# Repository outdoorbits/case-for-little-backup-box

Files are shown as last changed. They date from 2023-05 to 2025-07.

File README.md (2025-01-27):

# Case for little backup box

This project provides a housings for little backup box based on a <a href="Raspberry_Pi_zero_2W">Raspberry Pi zero 2W</a>, <a href="Raspberry_Pi_4">Raspberry Pi 4B</a> or <a href="Raspberry_Pi_5">Raspberry Pi 5</a>.<br>

## Housings for Raspberry Pi 4B and Raspberry Pi 5
They are based on a 3D drawing on the <a href="https://www.freecad.org">freeCAD</a> platform. This drawing can be easily adjusted using an integrated table of dimensions.<br>
<br>
<br>
For more information visit <a href="https://github.com/outdoorbits/little-backup-box">outdoorbits/little-backup-box</a>. In lbb's <a href="https://github.com/outdoorbits/little-backup-box/wiki">Wiki</a> you will find all information needed to plug it all together.</a>
<br>
<figure align="center">
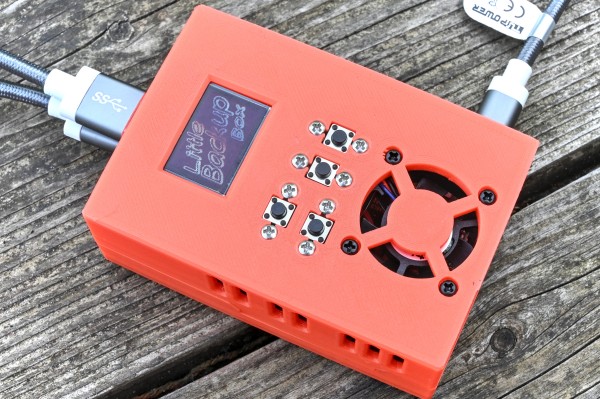
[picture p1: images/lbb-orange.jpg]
	
	<figcaption>Little Backup Box in this case, including a ssd1331 color display, buttons for menu-navigation and a pwm-controlled fan</figcaption>
</figure>
<br>
<h2>The standard drawings assumes the following components:</h2>
<ol>
	<li>Raspberry Pi 4 Model B or Raspberry Pi 5</li>
	<li>Display ssd1331 (RGB color display with 96x64 pixels, 1.3&quot;)</li>
	<li>Fan having external dimensions 30x30mm, hole spacing 24mm; prefer PMW-versions</li>
	<li>Micro key buttons 6x6 mm2, mounted on a board</li>
	<li>15 pieces of jumper wire, female</li>
	<li>4 screws M2.5 x 20 mm for the case</li>
	<li>8 screws M2.0 x 6 mm and nuts for the buttons</li>
	<li>Hot glue to stick the display</li>
</ol>

<h2>Customize drawing</h2>
If you use different hardware components, you can adapt the drawing.
It's (relatively) easy to adjust dimensions:
<ol>
	<li>Open the FCStd file with freeCAD</li>
	<li>Open the "dim" spreadsheet in the tree view</li>
	<li>Change the appropriate dimensions</li>
	<li>Mark the respective body in the tree view (e.g. "Bottom")</li>
	<li>Export the stl file (File - export...)</li>
</ol>

<br>
<figure align="center">
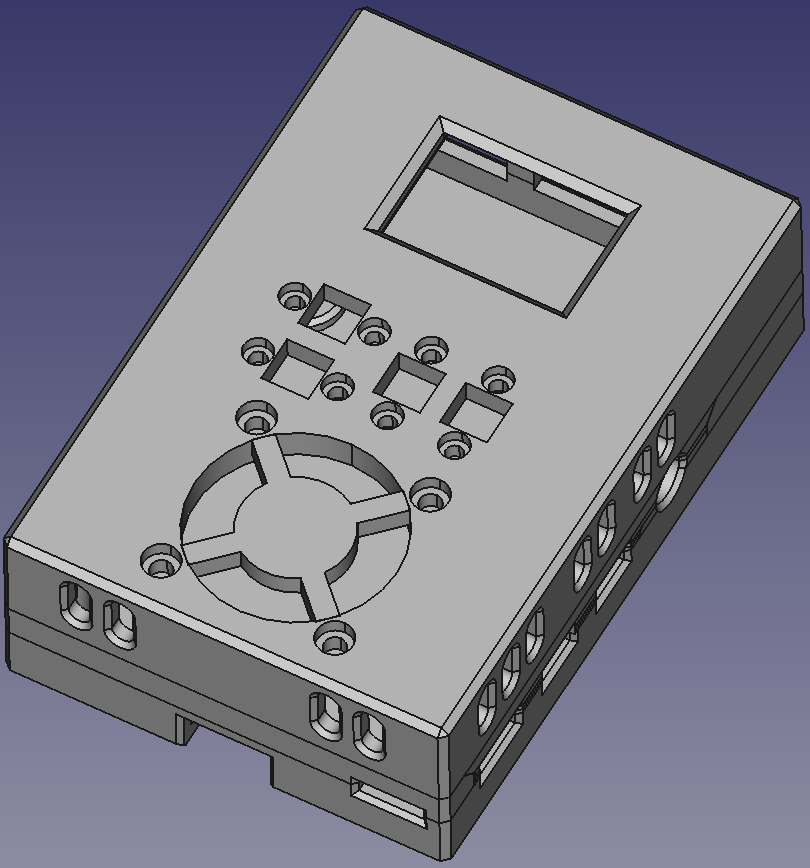
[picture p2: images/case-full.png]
	
	<figcaption>The whole case</figcaption>
</figure>

<figure align="center">
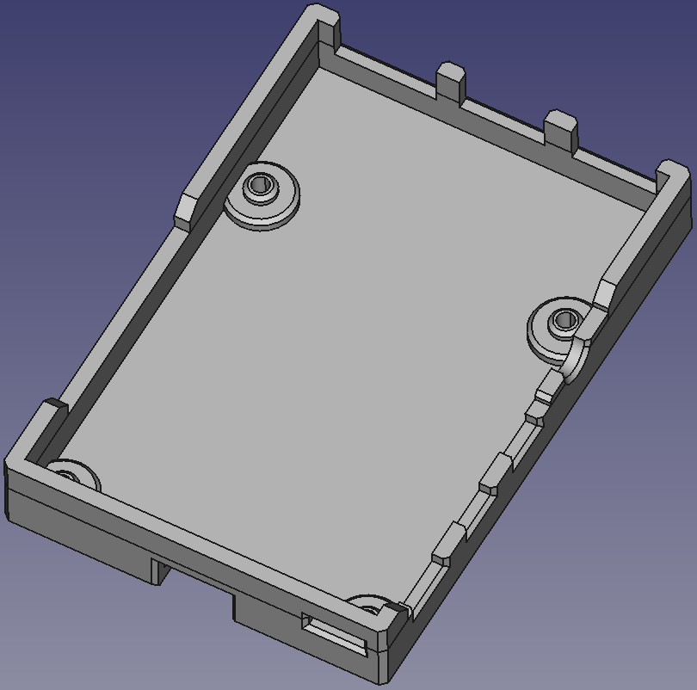
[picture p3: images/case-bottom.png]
	
	<figcaption>The bottom</figcaption>
</figure>

<figure align="center">
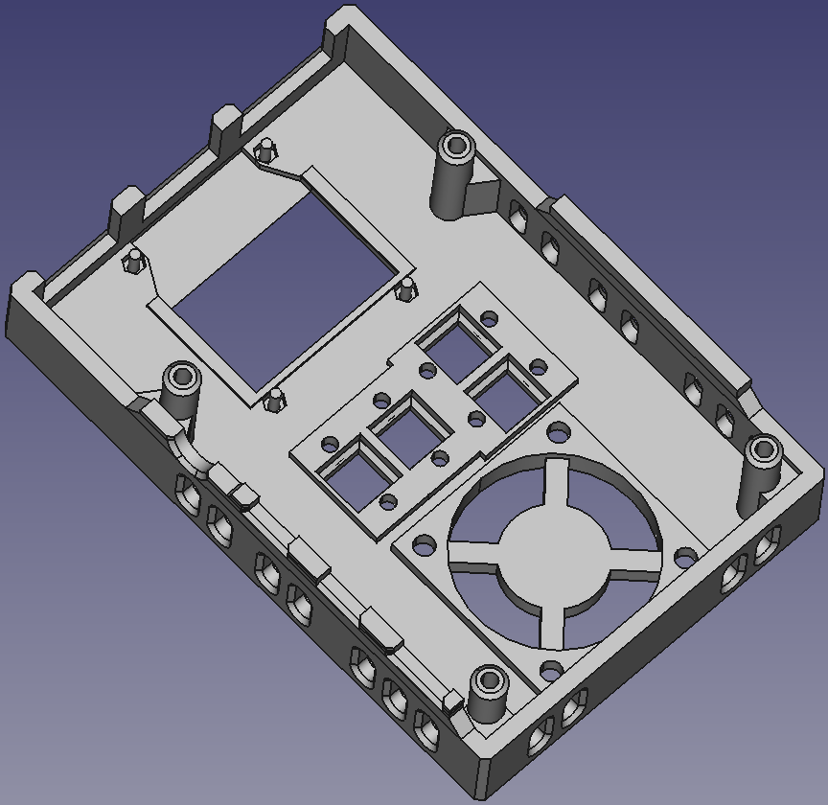
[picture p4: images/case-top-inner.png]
	
	<figcaption>Inside view of the top</figcaption>
</figure>

<figure align="center">
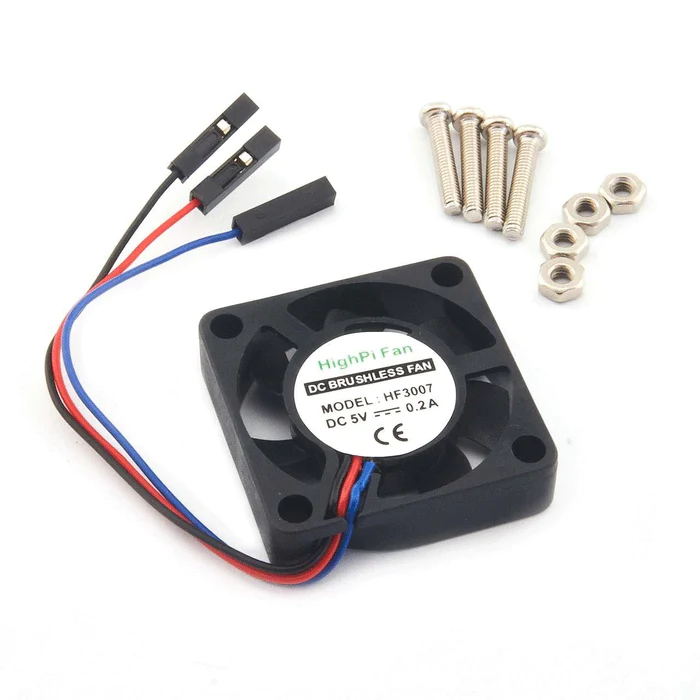
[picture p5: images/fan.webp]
	
	<figcaption>Fan, look for &quot;<a href="https://thepihut.com/products/highpi-pro-5v-fan-software-controlled">5V Fan - Software-Controlled</a>&quot;</figcaption>
</figure>

<figure align="center">
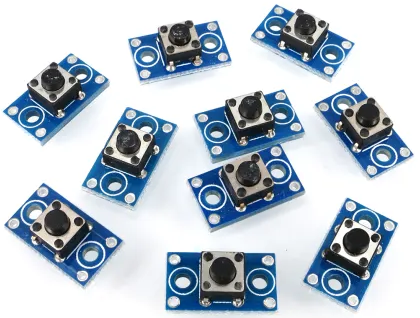
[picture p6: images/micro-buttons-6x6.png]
	
	<figcaption>Mico buttons, look for &quot;<a href="https://eckstein-shop.de/10xMicroKeyTaster6x6mmButtonsModuleRastermaC39F22C54mm12V2F50mA">Micro key button</a>&quot;</figcaption>
</figure>

## Housing for Raspberry Pi zero 2W
<figure>
	<a href="Raspberry_Pi_zero_2W">
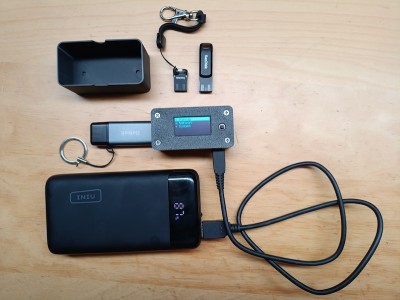
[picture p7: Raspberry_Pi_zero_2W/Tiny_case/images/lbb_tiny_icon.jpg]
		
	</a>
	<figcaption>Ultra tiny and well protected housing for Raspberry Pi 2W</figcaption>
</figure><br />
<br />
<br />

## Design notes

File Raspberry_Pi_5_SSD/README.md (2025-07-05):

[Thelightdecides](https://github.com/thelightdecides) presents several highly interesting versions of Little Backup Box on his [website](https://www.thelightdecides.com/travel-photography-blog/little-backup-box-simple-reliable-backup). A highlight is likely the version with an integrated actively cooled SSD and improved power supply.

The site is very clearly laid out and, in addition to the 3D printing files, also offers parts lists and richly illustrated assembly instructions. Great job!

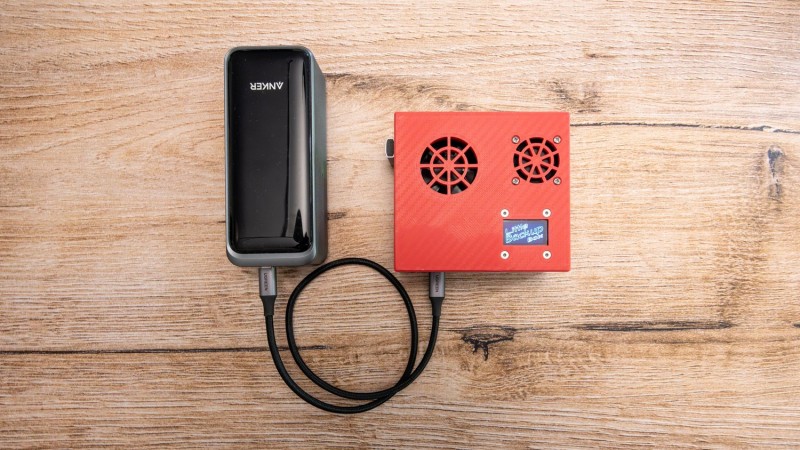
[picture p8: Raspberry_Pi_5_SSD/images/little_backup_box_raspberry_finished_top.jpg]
Housing for Raspberry Pi 5, SSD included
<BR CLEAR="all">

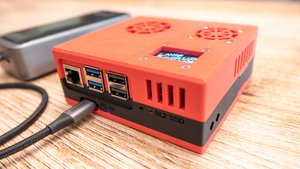
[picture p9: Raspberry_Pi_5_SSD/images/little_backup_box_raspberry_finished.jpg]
Housing for Raspberry Pi 5, SSD included
<BR CLEAR="all">

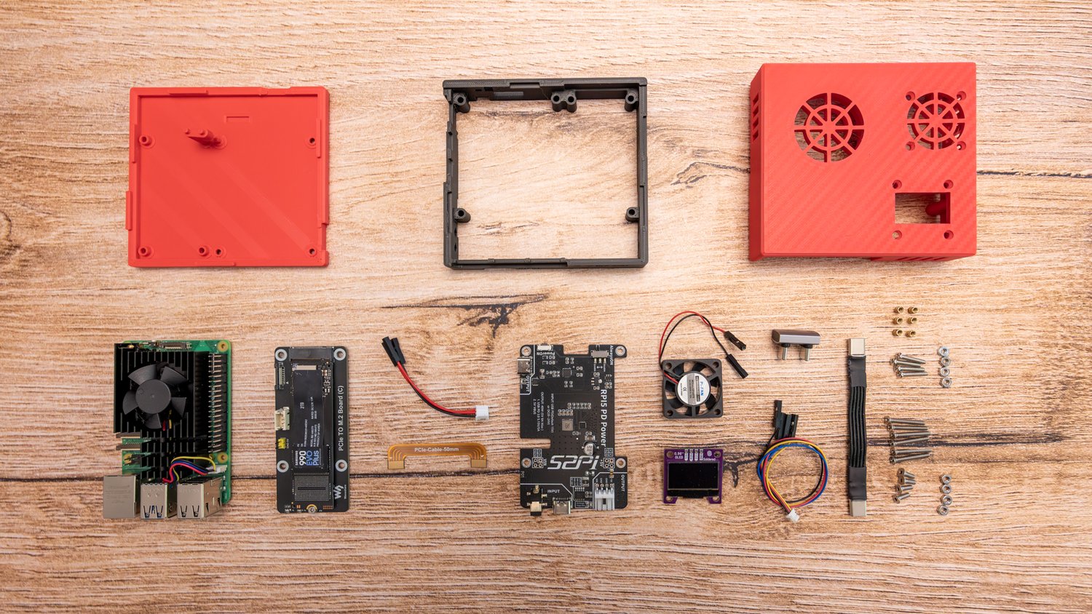
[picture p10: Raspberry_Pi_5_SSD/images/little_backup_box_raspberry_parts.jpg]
Housing for Raspberry Pi 5, SSD included
<BR CLEAR="all">

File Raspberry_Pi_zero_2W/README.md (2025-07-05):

# Solutions with Raspberry Pi Zero 2W

Many thanks to <a href="https://github.com/SigmaFred">SigmaFred</a>

|**<a href="https://github.com/outdoorbits/case-for-little-backup-box/tree/5c32135e73a34b2bc7892bdcb380beba48f0bea3/Raspberry_Pi_zero_2W/Tiny_case">Tiny Case:</a> A really tiny solution**|**<a href="https://github.com/outdoorbits/case-for-little-backup-box/tree/5c32135e73a34b2bc7892bdcb380beba48f0bea3/Raspberry_Pi_zero_2W/Battery_case">Battery Case:</a> A small battery driven solution**|
|:---|:---|
|*With display and joystick control in a tiny, practical and robust housing*|*With UPS battery, display and joystick control in a small, practical and robust housing*|
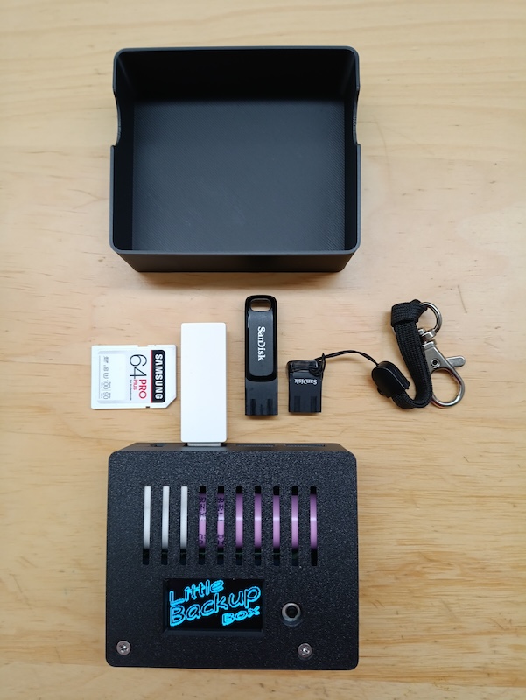
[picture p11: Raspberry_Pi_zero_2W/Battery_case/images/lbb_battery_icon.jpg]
| |  |
<br />
<br />

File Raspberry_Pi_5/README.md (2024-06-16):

# Case for Raspberry Pi 5!
It uses the orignal Raspberry Pi Active Cooler and is a few millimeters flatter than the Raspberry 4 case.
Because of the fan, the space inside is very limited. Highly felxible silicone cables can help a lot!

The actual case uses all the other components of the RPi 4 version, excepted the fan.
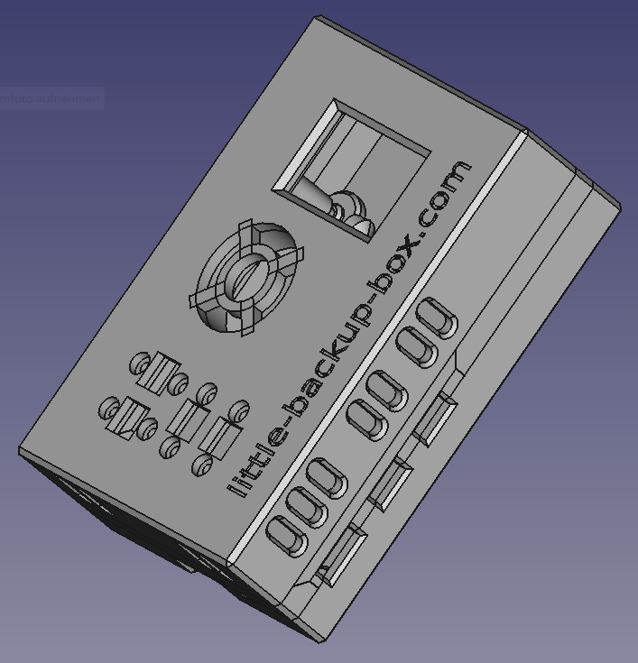
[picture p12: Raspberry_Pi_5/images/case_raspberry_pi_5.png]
Case for Raspberry Pi 5


## Variant for using an integrated NVMe SSD

Caution: When accessing large amounts of data, the SSD can easily overheat. There is a real risk of data loss! This variant should not be used without active cooling of the SSD. Perhaps a corresponding SSD adapter board will come onto the market.

If an SSD expansion is to be integrated, only the bottom of the housing needs to be replaced. This will be some 10 mm higher than the standard.

After modifications <a href="https://geekworm.com/products/x1002">Geekworm X1002</a> can be used. But it needs to be modified:
- Field 2280 does not contain any wires. It needs to be shortened otherwise the board would be longer than the Pi. However, this means that SSDs of size 2280 can no longer be used
- The four mounting threads that are used to attach the Raspberry Pi must be drilled out to 2.5 mm.

Additional material for attaching the M.2 SSD to the board: \
1 screw 6mm  M2.5 (or M2.0) \
2 nuts M2.5 (or M2.0)

For the case:
4 screws M2.5 x 30 mm (replacing the M2.5 x 20 mm of the standard case)

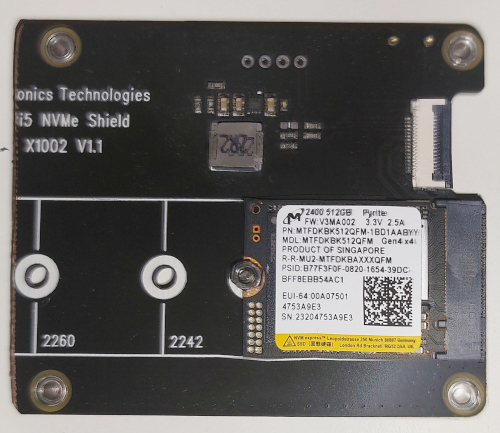
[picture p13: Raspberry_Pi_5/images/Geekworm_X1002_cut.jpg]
The Geekworm X1002, shortened

The Geekworm X1002, shortened

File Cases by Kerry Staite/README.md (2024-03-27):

<h1>Cases for little backup box by Kerry Staite</h1>
Kerry Staite created this cases for Raspberry Pi 4 and Raspberry Pi zero.

Thank you!

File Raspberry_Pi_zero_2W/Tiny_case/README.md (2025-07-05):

# A really tiny solution
Raspberry Pi 2W with display and joystick control in a practical and robust housing

Many thanks to <a href="https://github.com/SigmaFred">SigmaFred</a>

<figure>
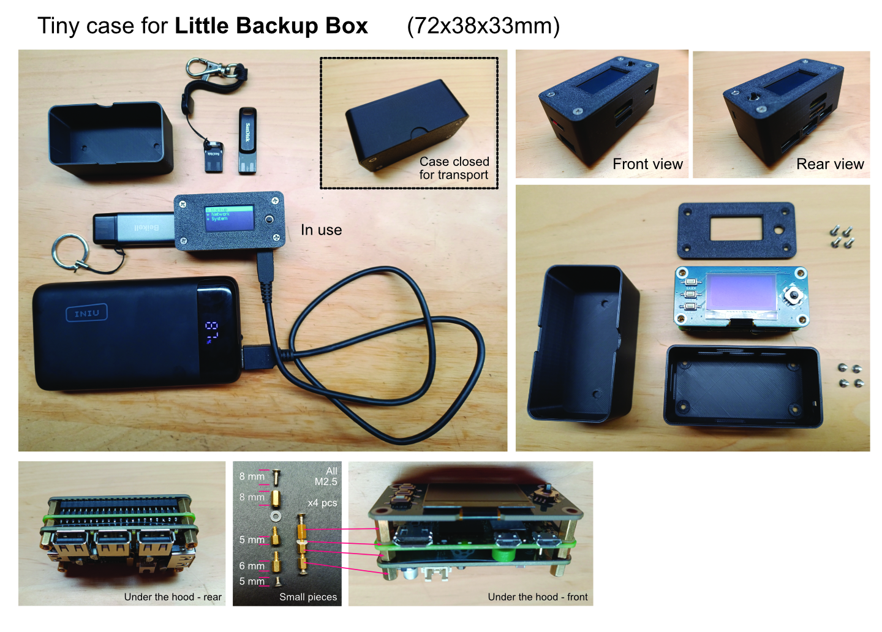
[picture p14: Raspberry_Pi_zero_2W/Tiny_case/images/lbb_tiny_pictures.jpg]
	
	<figcaption>Overview</figcaption>
</figure><br />
<br />
<br />
<figure>
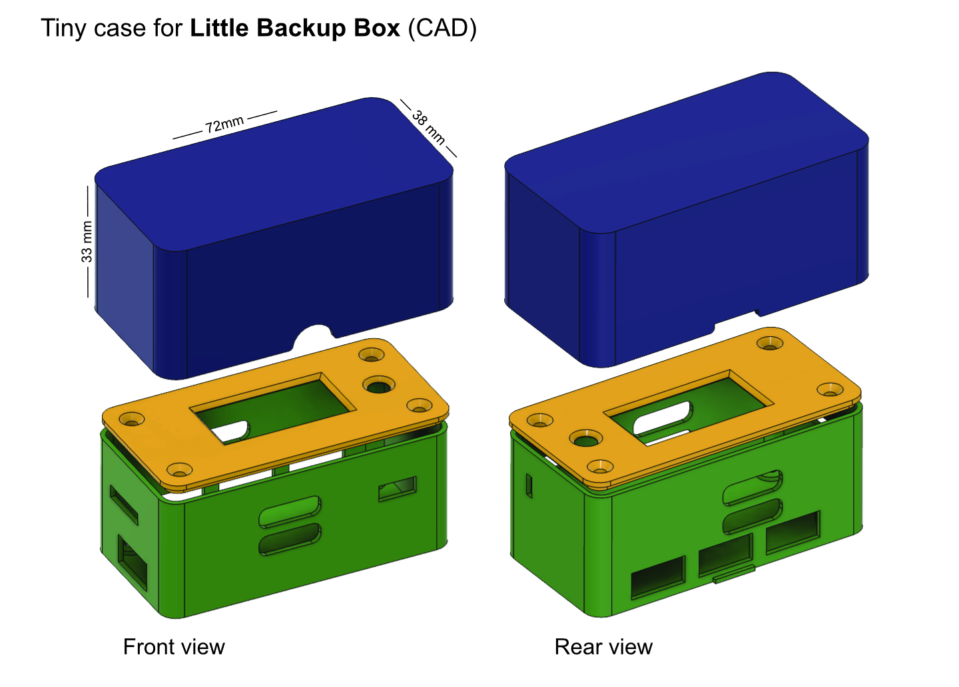
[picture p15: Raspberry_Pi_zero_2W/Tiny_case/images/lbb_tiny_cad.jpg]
	
	<figcaption>CAD drawing</figcaption>
</figure><br />
<br />
There are two slightly different variants: The standard version has a gap of 0.05 mm between the Raspberry Pi and the case. Depending on the print quality, this may be a bit tight, so <a href="https://github.com/SigmaFred">SigmaFred</a> has provided a second version with a slightly wider gap of 0.1 mm. Both are located in the stl folder.

## What you need
<ul>
	<li>Pi Zero 2W</li>
	<li>Zero4U USB Hub with Pogo-Pins (UUGear)</li>
	<li>1.3" OLED Display HAT for Raspberry Pi 128x64 (Waveshare)</li>
	<li>Small parts, see image above</li>
</ul>

## Setup
### Display
Driver: SH1106\
Interface: SPI\
SPI port: 0\
Horizontal resolution: 128\
Vertical resolution: 64\
Color: Black-and-white

### Control buttons
Variant: 3

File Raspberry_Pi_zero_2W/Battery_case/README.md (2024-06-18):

# A small battery driven solution
Raspberry Pi 2W with UPS battery, display and joystick control in a practical and robust housing

Many thanks to <a href="https://github.com/SigmaFred">SigmaFred</a>

|**Little Backup Box running**|**Little Backup Box closed**|
|:---:|:---:|
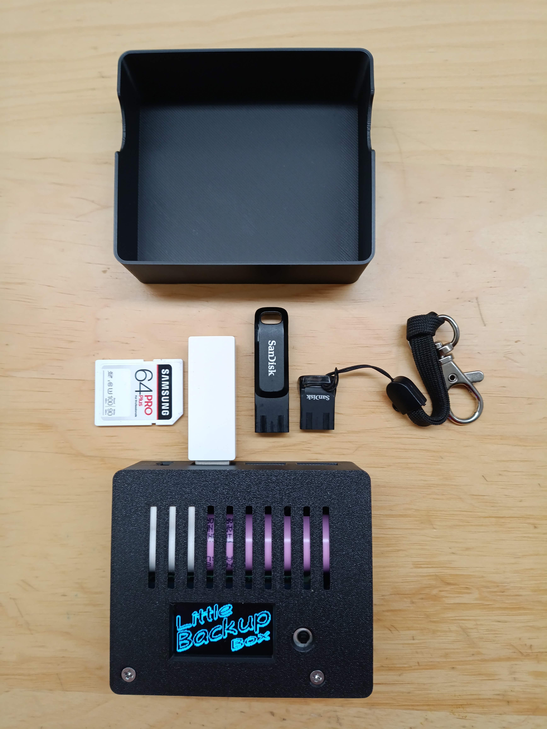
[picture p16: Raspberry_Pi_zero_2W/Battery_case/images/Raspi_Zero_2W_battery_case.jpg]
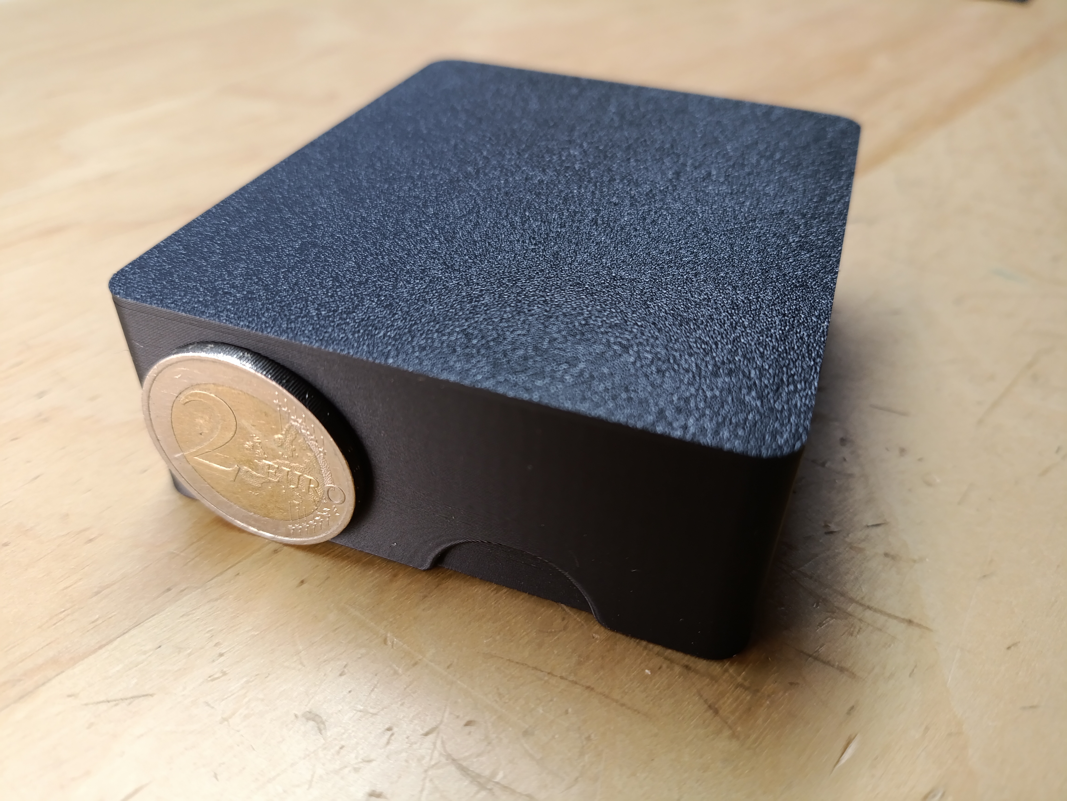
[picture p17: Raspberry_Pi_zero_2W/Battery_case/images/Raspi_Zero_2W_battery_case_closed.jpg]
|  |  |
<br />
<br />
<figure>
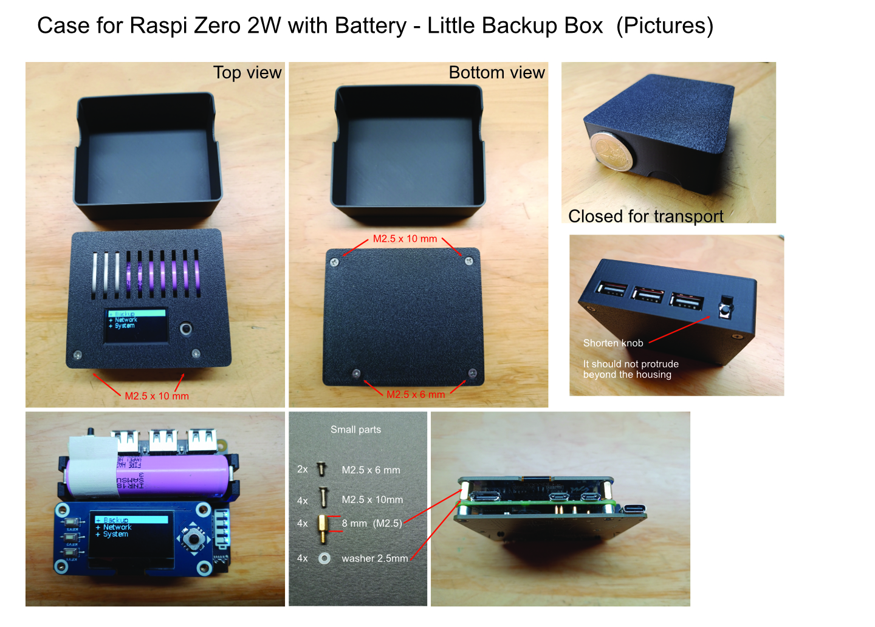
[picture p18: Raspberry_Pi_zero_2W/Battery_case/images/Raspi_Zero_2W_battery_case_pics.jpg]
	
	<figcaption>Overview in pictures</figcaption>
</figure><br />
<br />
<br />
<figure>
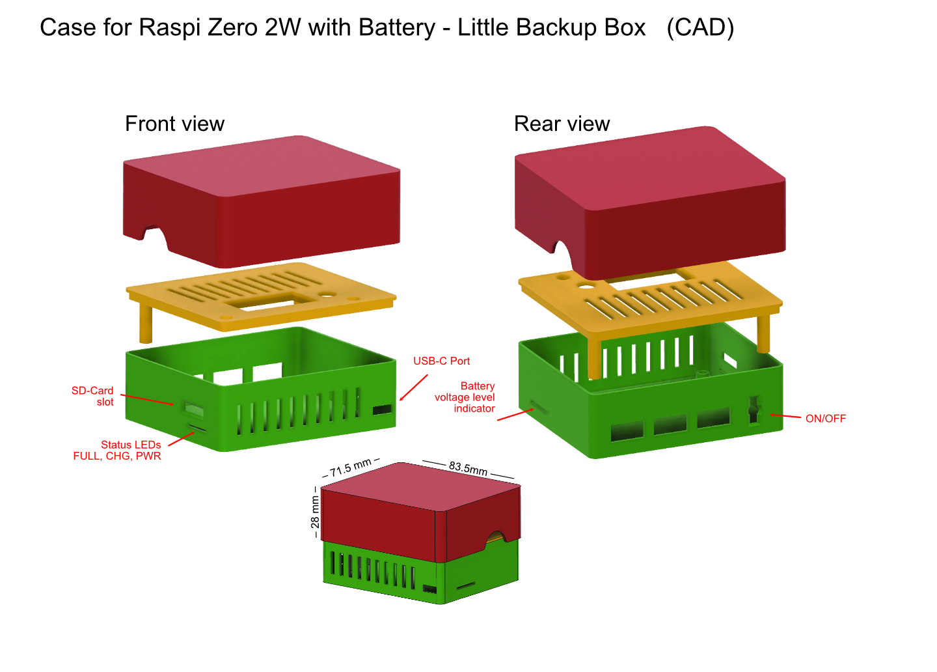
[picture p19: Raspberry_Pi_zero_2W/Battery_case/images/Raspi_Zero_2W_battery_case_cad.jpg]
	
	<figcaption>CAD details</figcaption>
</figure><br />
<br />

## What you need
<ul>
	<li>1.3" OLED Display HAT for Raspberry Pi 128x64 (Waveshare)</li>
	<li>Pi Zero 2W</li>
	<li>Geekworm Ultra-thin 18650 UPS & USB HUB Shield (X306) for Raspberry Pi Zero 2 W / Zero W <br /> Note: you will need V1.2 or lower, as from V1.3 they have omitted the 3 USB ports </li>
	<li>Type 18650 battery (e.g. Samsung INR18650-35E)</li>
	<li>Small parts, see image</li>
</ul>

## Setup
### Display
Driver: SH1106\
Interface: SPI\
SPI port: 0\
Horizontal resolution: 128\
Vertical resolution: 64\
Color: Black-and-white

### Control buttons
Variant: 3

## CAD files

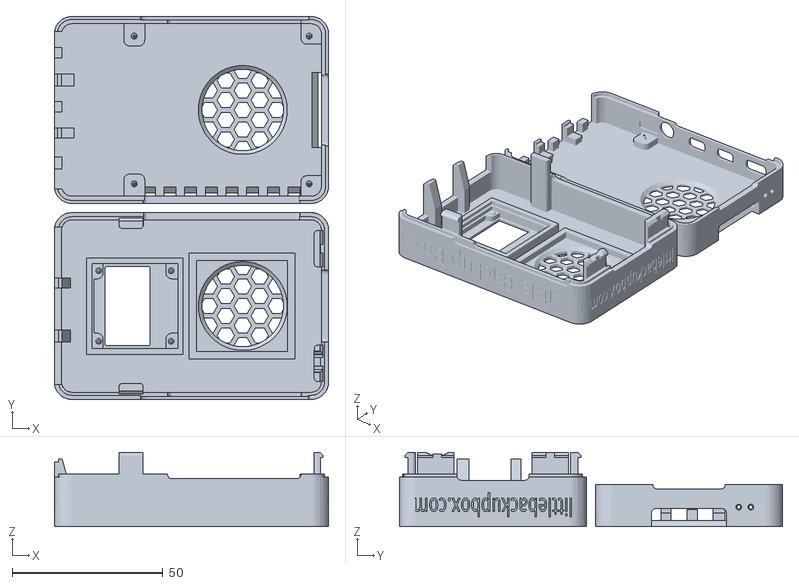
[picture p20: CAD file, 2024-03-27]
Cases by Kerry Staite/little-backup-box-rpi4.stl
91.0 x 127.0 x 24.7

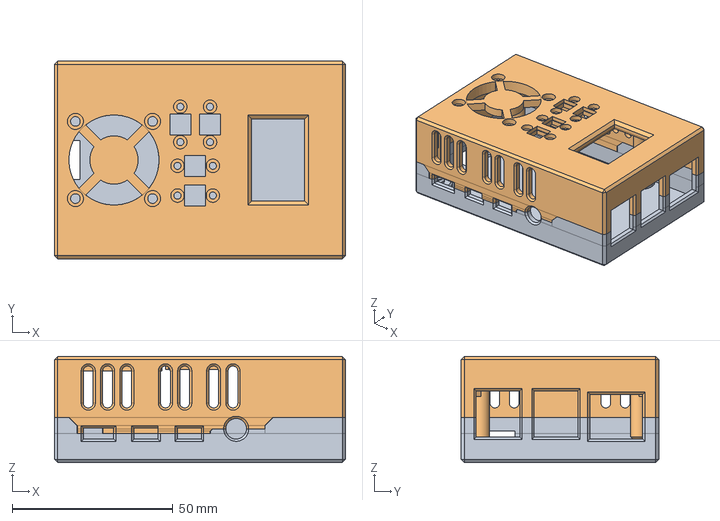
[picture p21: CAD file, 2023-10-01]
Raspberry_Pi_4/lbb-case.FCStd
90.5 x 61.5 x 33.0 mm
Bottom
Top

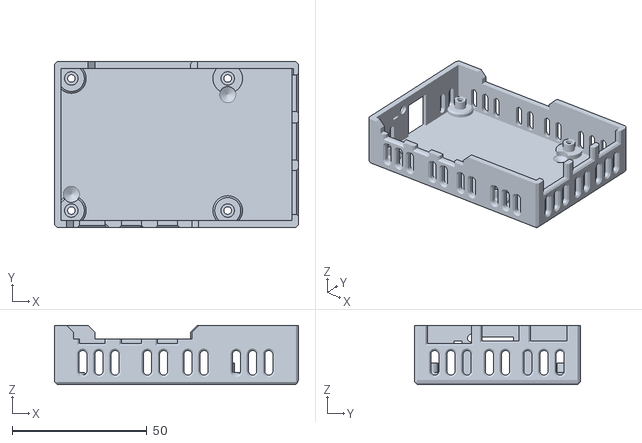
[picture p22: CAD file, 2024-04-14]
Raspberry_Pi_5/lbb-case RPi5-Bottom_NVMe.stl
90.5 x 61.5 x 21.9

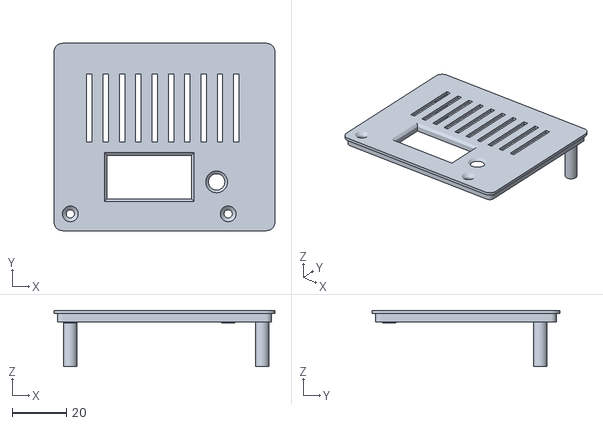
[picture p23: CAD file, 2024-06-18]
Raspberry_Pi_zero_2W/Battery_case/stl/top_Zero2W_battery_case.stl
81.2 x 68.9 x 20.7

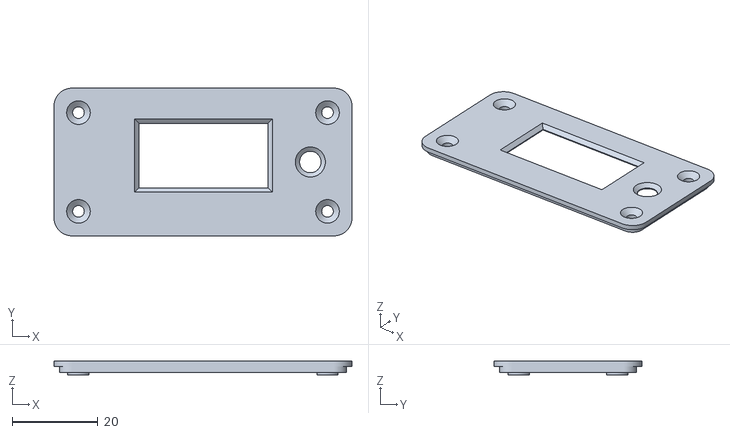
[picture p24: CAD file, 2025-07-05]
Raspberry_Pi_zero_2W/Tiny_case/stl/expanded gap/RaspiZero2W_top_gap_0.1mm.stl
69.4 x 34.4 x 3.20

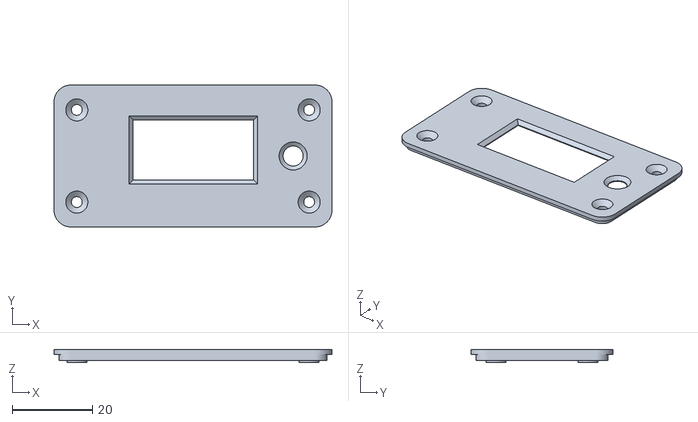
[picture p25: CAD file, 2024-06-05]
Raspberry_Pi_zero_2W/Tiny_case/stl/LBB_RaspiZero2W_top_zero4u_1.0.stl
69.4 x 35.4 x 3.20

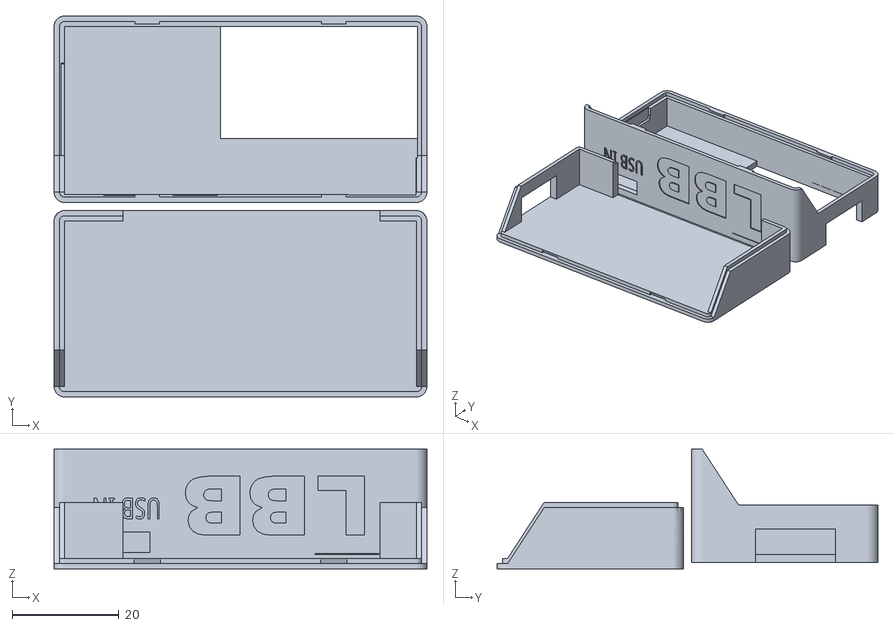
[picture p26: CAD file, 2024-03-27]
Cases by Kerry Staite/little-backup-box-zero-pioled-zero4u.stl
70.0 x 71.5 x 22.5

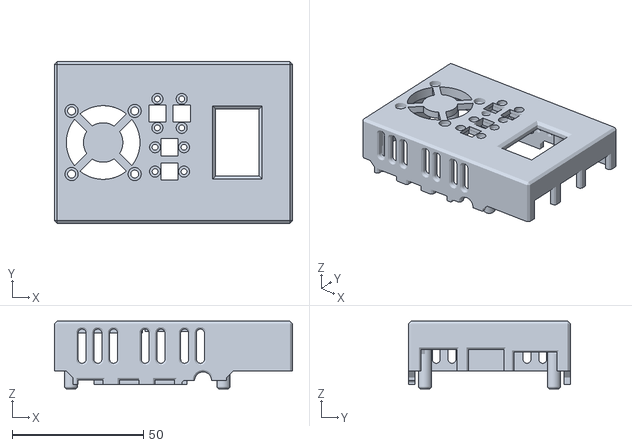
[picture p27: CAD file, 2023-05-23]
Raspberry_Pi_4/lbb-case-Top.stl
90.5 x 61.5 x 25.7

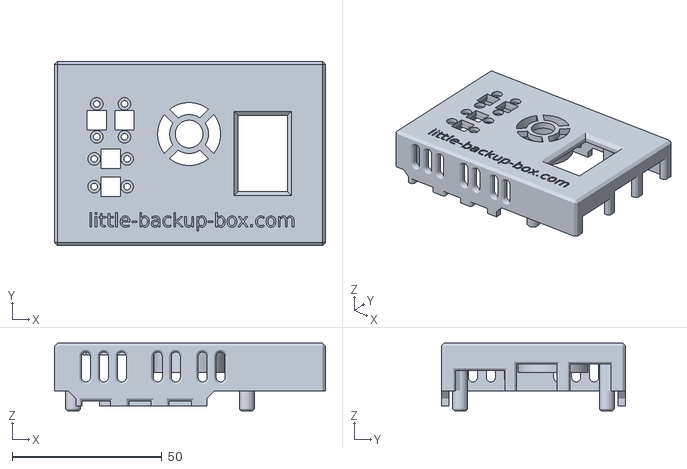
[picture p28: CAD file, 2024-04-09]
Raspberry_Pi_5/lbb-case RPi5-Top.stl
90.5 x 61.5 x 22.7

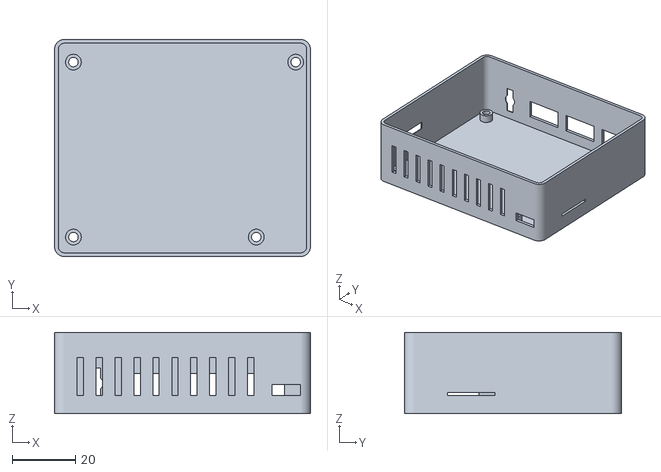
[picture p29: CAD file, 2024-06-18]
Raspberry_Pi_zero_2W/Battery_case/stl/bottom_Zero2W_battery_case.stl
81.2 x 68.9 x 25.7

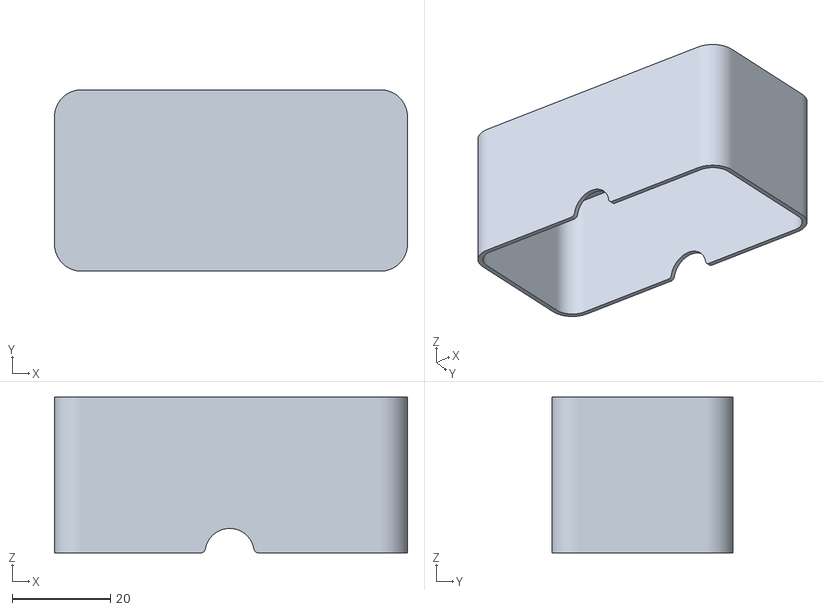
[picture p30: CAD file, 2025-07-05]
Raspberry_Pi_zero_2W/Tiny_case/stl/expanded gap/RaspiZero2W_cover_gap_0.1mm.stl
72.0 x 37.0 x 31.8

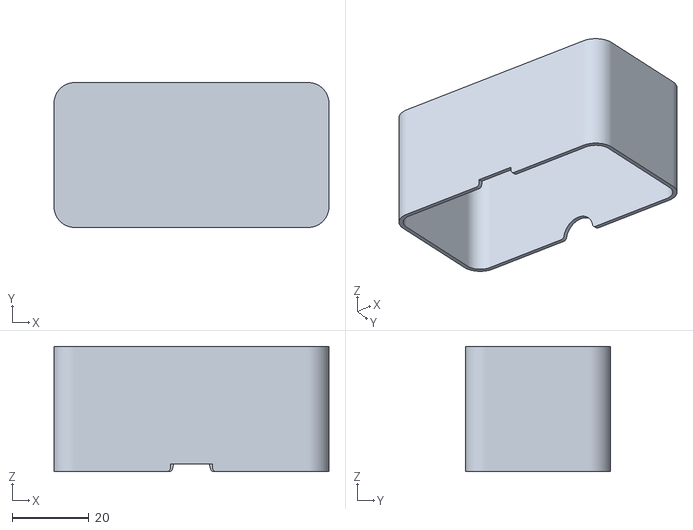
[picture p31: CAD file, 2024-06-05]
Raspberry_Pi_zero_2W/Tiny_case/stl/LBB_RaspiZero2W_cover_zero4u_1.0.stl
71.9 x 37.9 x 32.8

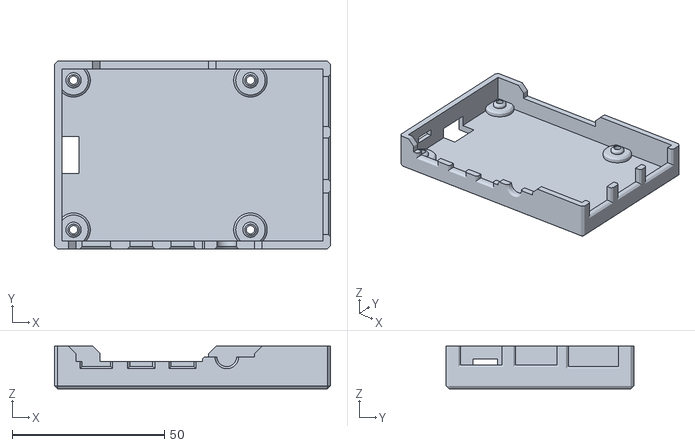
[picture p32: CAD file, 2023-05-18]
Raspberry_Pi_4/lbb-case-Bottom.stl
90.5 x 61.5 x 14.0

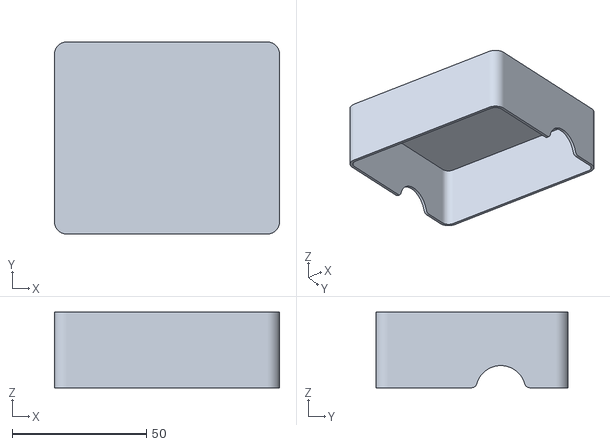
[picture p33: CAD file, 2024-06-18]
Raspberry_Pi_zero_2W/Battery_case/stl/cover_Zero2W_battery_case.stl
83.7 x 71.4 x 28.1

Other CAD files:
Raspberry_Pi_5/lbb-case RPi5-Bottom.stl
Raspberry_Pi_zero_2W/Tiny_case/stl/expanded gap/RaspiZero2W_bottom_gap_0.1mm.stl
Raspberry_Pi_zero_2W/Tiny_case/stl/LBB_RaspiZero2W_bottom_zero4u_1.0.stl
Raspberry_Pi_5/lbb-case RPi5.FCStd
Raspberry_Pi_4/lbb-case-mounting material washer x8.stl
Raspberry_Pi_5/lbb-case RPi5-power_button.stl
Raspberry_Pi_5/lbb-case no-buttons RPi5-Bottom.stl
Raspberry_Pi_5/lbb-case no-buttons RPi5-Top.stl
Raspberry_Pi_5/lbb-case no-buttons RPi5.FCStd
Raspberry_Pi_zero_2W/Battery_case/stl/Raspi Zero 2W Case Battery V1.f3d
Raspberry_Pi_zero_2W/Tiny_case/stl/Raspi Zero 2W Case Zero4U V1.0.f3d

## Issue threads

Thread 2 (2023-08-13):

Cannot see anything in freecad

dietrest, 2023-08-13:
If I load/import https://github.com/outdoorbits/case-for-little-backup-box/blob/main/lbb-case-Bottom.stl or the other stl files in freecad 0.21.0 on Manjaro Linux I can't see anything only an empty "sheet". What is going on ?

outdoorbits, 2023-08-13:
The freecad file is the lbb-case.FCStd.

dietrest, 2023-08-14:
I've downloaded the zip a second time and with debian Iwas able to open the files with freecad. My Windows refuses to start freecad after Install :-(

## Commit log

2023-05-15 primary version
    [lbb-case-Bottom.stl, lbb-case-Top.stl, lbb-case-mounting material washer x8.stl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]
2023-05-18 improved tolerance for deviating display dimensions; improved fitting of the buttons
    [lbb-case-Top.stl, lbb-case.FCStd]
2023-05-18 correct position of LEDs
    [lbb-case-Bottom.stl, lbb-case.FCStd]
2023-05-18 increase Top-height to allow fan (with screws and nuts) and cooler
    [lbb-case-Top.stl, lbb-case.FCStd]
2023-05-22 minor tweaks, tested version
    [lbb-case-Top.stl, lbb-case.FCStd]
2023-05-23 add sunks under button solder points
    [lbb-case-Top.stl, lbb-case.FCStd]
2023-10-01 add Raspberry Pi 5 case candidate
    [lbb-case-Bottom.stl, lbb-case-Top.stl, lbb-case-mounting material washer x8.stl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]
2023-12-27 Raspberry Pi 5. Better adapted
    [lbb-case RPi5-Bottom.stl, lbb-case RPi5-Top.stl, lbb-case RPi5-power_button.stl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]
2024-01-04 add top without buttons
    [lbb-case RPi5-Bottom.stl, lbb-case RPi5-Top.stl, lbb-case RPi5.FCStd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]
2024-01-16 change button screws length, add additional ventilation slots
    [lbb-case RPi5-Top.stl, lbb-case RPi5.FCStd]
2024-01-22 Case for Raspberry Pi 5 is finished.
2024-01-28 better fit of USB2,0 USB3 and the fan
    [lbb-case RPi5-Bottom.stl, lbb-case RPi5-Top.stl, lbb-case RPi5.FCStd]
2024-01-30 add Raspberry 5 support information
    [lbb-case RPi5.FCStd]
2024-01-30 fix power button and increase top height by 1 mm
    [lbb-case RPi5-Bottom.stl, lbb-case RPi5-Top.stl, lbb-case RPi5-power_button.stl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]
2024-02-04 improve stability of screw sockets
    [lbb-case RPi5-Bottom.stl, lbb-case RPi5-Top.stl]
2024-02-06 precise display dimensions
    [lbb-case RPi5-Top.stl]
2024-03-27 migrate Kerry Staites cases
    [little-backup-box-rpi4.stl, little-backup-box-zero-pioled-zero4u.stl]
2024-06-05 add case for zero 2W by SigmaFred
    [LBB_RaspiZero2W_bottom_zero4u_1.0.stl, LBB_RaspiZero2W_cover_zero4u_1.0.stl, LBB_RaspiZero2W_top_zero4u_1.0.stl]
2024-06-08 add cad file
    [Raspi Zero 2W Case Zero4U V1.0.f3d]
2024-06-13 Create README.md
    Add info on new case for LBB
2024-06-13 Fusion 360 file
    Created with free, non commercial edition
    [Raspi Zero 2W Case Battery V1.f3d]
2024-06-18 Delete Raspberry_Pi_zero_2W/Tiny_case/images/empty.doc
    remove interim file
2024-06-18 Delete Raspberry_Pi_zero_2W/Tiny_case/stl/empty.doc
    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
2024-06-18 Delete Raspberry_Pi_zero_2W/Raspi Zero 2W Case Zero4U V1.0.f3d
    as moved into different subdirectory
    [Raspi Zero 2W Case Zero4U V1.0.f3d]
2024-06-18 Delete Raspberry_Pi_zero_2W/stl directory
    files moved
    [LBB_RaspiZero2W_bottom_zero4u_1.0.stl, LBB_RaspiZero2W_cover_zero4u_1.0.stl, LBB_RaspiZero2W_top_zero4u_1.0.stl]
2025-07-05 Pi zero 2W: Add case with expandet gap
    [RaspiZero2W_bottom_gap_0.1mm.stl, RaspiZero2W_cover_gap_0.1mm.stl, RaspiZero2W_top_gap_0.1mm.stl]
